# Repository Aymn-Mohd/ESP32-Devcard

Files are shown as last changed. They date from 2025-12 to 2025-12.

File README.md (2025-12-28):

# ESP32DevCard v1 — Credit-Card Sized Powerhouse

A deployment-oriented ESP32-S3 development board for engineers building systems, not desk toys. Real power delivery, integrated sensing, and full breakout in a compact 70 × 50 mm footprint.

The goal: eliminate the wiring mess that causes 80% of prototype failures.

---

## Why This Exists

Most ESP32 boards assume your prototype ends at a breadboard. The moment you attach motors, LED arrays, or anything drawing real current, they fall apart.

This solves that problem directly:

* 4-layer stackup for signal and power integrity
* Multiple power injection points
* Clean grounding discipline and ESD protection
* On-board peripheral support for validation without external modules

This is the board you use when reliability matters from the first test.

---

## Core Capabilities

* ESP32-S3-MINI-1-N8 (Wi-Fi + BLE, dual core)
* ENS210 temperature/humidity sensor (I²C)
* WS2812B RGB indicator (GPIO48)
* USB-C for power/programming with protection circuitry
* 44 usable GPIOs on dual headers
* High-current 5V and 3.3V rails
* 4-layer PCB for controlled return paths

---

## Technical Specifications

| Parameter | Value |
| --- | --- |
| Dimensions | 70 × 50 mm |
| Layers | 4 |
| MCU Flash | 8 MB |
| Operating Voltage | 3.3 V |
| Status LED | WS2812B (GPIO48) |
| On-board Sensor | ENS210 |

---

## Getting Started

1. Plug in via USB-C
2. Flash using the ESP-IDF toolchain or PlatformIO
3. Access peripherals immediately (I²C sensor, indicator LED)

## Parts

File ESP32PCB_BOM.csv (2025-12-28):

Reference | Qty | Part# | Value | Footprint
U1 | 1 | ESP32-S3-MINI-1-N8 | - | ESP32-S3-MINI-1-N8:XCVR_ESP32-S3-MINI-1-N8
U2 | 1 | ESD7104MUTAG | - | Package_DFN_QFN:Diodes_UDFN-10_1.0x2.5mm_P0.5mm
U3 | 1 | TLV75801PDRVR | - | Package_SON:WSON-6-1EP_2x2mm_P0.65mm_EP1x1.6mm
U4 | 1 | ENS210-LQFM | - | Package_DFN_QFN:AMS_QFN-4-1EP_2x2mm_P0.95mm_EP0.7x1.6mm
BOOT1, RESET1 | 2 | PTS810 SJK 250 SMTR LFS | - | Button_Switch_SMD:SW_SPST_PTS810
JUSB1 | 1 | USB4105-GF-A | - | Connector_USB:USB_C_Receptacle_GCT_USB4105-xx-A_16P_TopMnt_Horizontal
D1 | 1 | COM-16347 | - | LED_SMD:LED_WS2812B_PLCC4_5.0x5.0mm_P3.2mm
D2 | 1 | 150060RS75000 | - | LED_SMD:LED_0603_1608Metric
J1, J3 | 2 | 61302211121 | - | Connector_PinHeader_2.54mm:PinHeader_1x22_P2.54mm_Vertical
C1, C3, C4, C5 | 4 | CC0603KRX7R7BB104 | 0.1uF | Capacitor_SMD:C_0603_1608Metric
C2, C6, C7 | 3 | CL10A106MQ8NNNC | 10uF | Capacitor_SMD:C_0603_1608Metric
R1, R2, R8 | 3 | RC0603FR-075K1L | 5.1k | Resistor_SMD:R_0603_1608Metric
R3, R4, R5 | 3 | RC0603FR-0710KL | 10k | Resistor_SMD:R_0603_1608Metric
R6 | 1 | RT0603BRD071ML | 1M | Resistor_SMD:R_0603_1608Metric
R7 | 1 | RC0603FR-07200KL | 200k | Resistor_SMD:R_0603_1608Metric

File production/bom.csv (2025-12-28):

Designator | Footprint | Quantity | Value | LCSC Part #
BOOT1, RESET1 | SW_SPST_PTS810 | 2 | ~
C1, C3, C4, C5 | 0603 | 4 | 0.1uF
C2, C6, C7 | 0603 | 3 | 10uF
D1 | LED_WS2812B_PLCC4_5.0x5.0mm_P3.2mm | 1 | WS2812B
D2 | 0603 | 1 | LED
J1, J3 | PinHeader_1x22_P2.54mm_Vertical | 2 | ~
J2, J4, J5 | PinHeader_1x03_P2.54mm_Vertical | 3 | Conn_01x03_Pin
JUSB1 | USB_C_Receptacle_GCT_USB4105-xx-A_16P_TopMnt_Horizontal | 1 | USB_C_Receptacle_USB2.0
R1, R2, R8 | 0603 | 3 | 5.1k
R3, R4, R5 | 0603 | 3 | 10k
R6 | 0603 | 1 | 1M
R7 | 0603 | 1 | 200k
U1 | XCVR_ESP32-S3-MINI-1-N8 | 1 | ESP32-S3-MINI-1-N8
U2 | Diodes_UDFN-10_1.0x2.5mm_P0.5mm | 1 | ESD7104MUTAG
U3 | WSON-6-1EP_2x2mm_P0.65mm_EP1x1.6mm | 1 | TLV75801PDRV
U4 | AMS_QFN-4-1EP_2x2mm_P0.95mm_EP0.7x1.6mm | 1 | ENS210

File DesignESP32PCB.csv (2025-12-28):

Id | Designator | Footprint | Quantity | Designation | Supplier and ref
1 | J5,J4,J2 | PinHeader_1x03_P2.54mm_Vertical | 3 | Conn_01x03_Pin
2 | R5,R4,R3 | R_0603_1608Metric | 3 | 10k
3 | C5,C1,C4,C3 | C_0603_1608Metric | 4 | 0.1uF
4 | D2 | LED_0603_1608Metric | 1 | LED
5 | R8,R2,R1 | R_0603_1608Metric | 3 | 5.1k
6 | R6 | R_0603_1608Metric | 1 | 1M
7 | U2 | Diodes_UDFN-10_1.0x2.5mm_P0.5mm | 1 | ESD7104MUTAG
8 | C7,C6,C2 | C_0603_1608Metric | 3 | 10uF
9 | J1,J3 | PinHeader_1x22_P2.54mm_Vertical | 2 | ~
10 | R7 | R_0603_1608Metric | 1 | 200k
11 | RESET1,BOOT1 | SW_SPST_PTS810 | 2 | ~
12 | U1 | XCVR_ESP32-S3-MINI-1-N8 | 1 | ESP32-S3-MINI-1-N8
13 | D1 | LED_WS2812B_PLCC4_5.0x5.0mm_P3.2mm | 1 | WS2812B
14 | U3 | WSON-6-1EP_2x2mm_P0.65mm_EP1x1.6mm | 1 | TLV75801PDRV
15 | U4 | AMS_QFN-4-1EP_2x2mm_P0.95mm_EP0.7x1.6mm | 1 | ENS210
16 | JUSB1 | USB_C_Receptacle_GCT_USB4105-xx-A_16P_TopMnt_Horizontal | 1 | USB_C_Receptacle_USB2.0

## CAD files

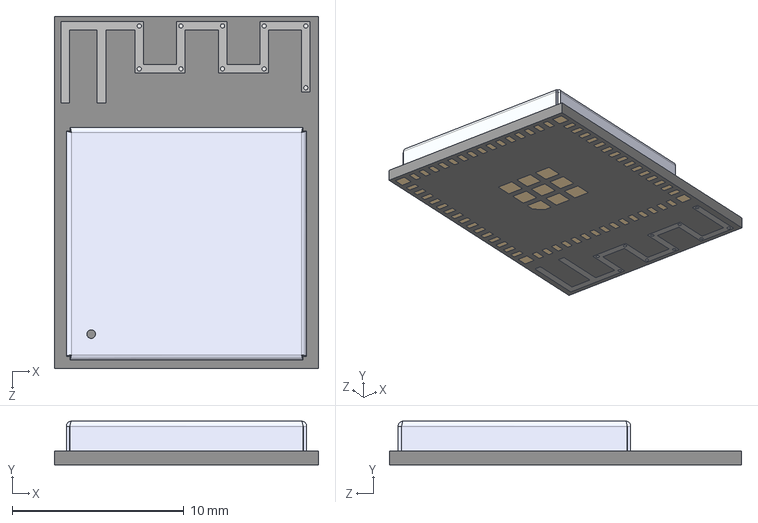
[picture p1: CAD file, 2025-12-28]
ESP32_S3_MINI_1_N8/ESP32-S3-MINI-1-N8.step
15.4 x 2.55 x 20.5 mm

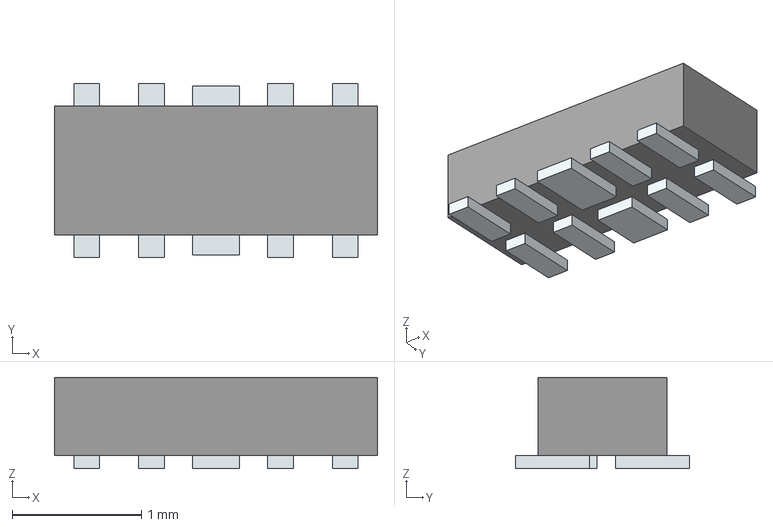
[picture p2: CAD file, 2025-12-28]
LIB_D3V3XA4B10LP-7/3D_MODEL_D3V3XA4B10LP-7.stp
2.50 x 1.35 x 0.705 mm
Pins

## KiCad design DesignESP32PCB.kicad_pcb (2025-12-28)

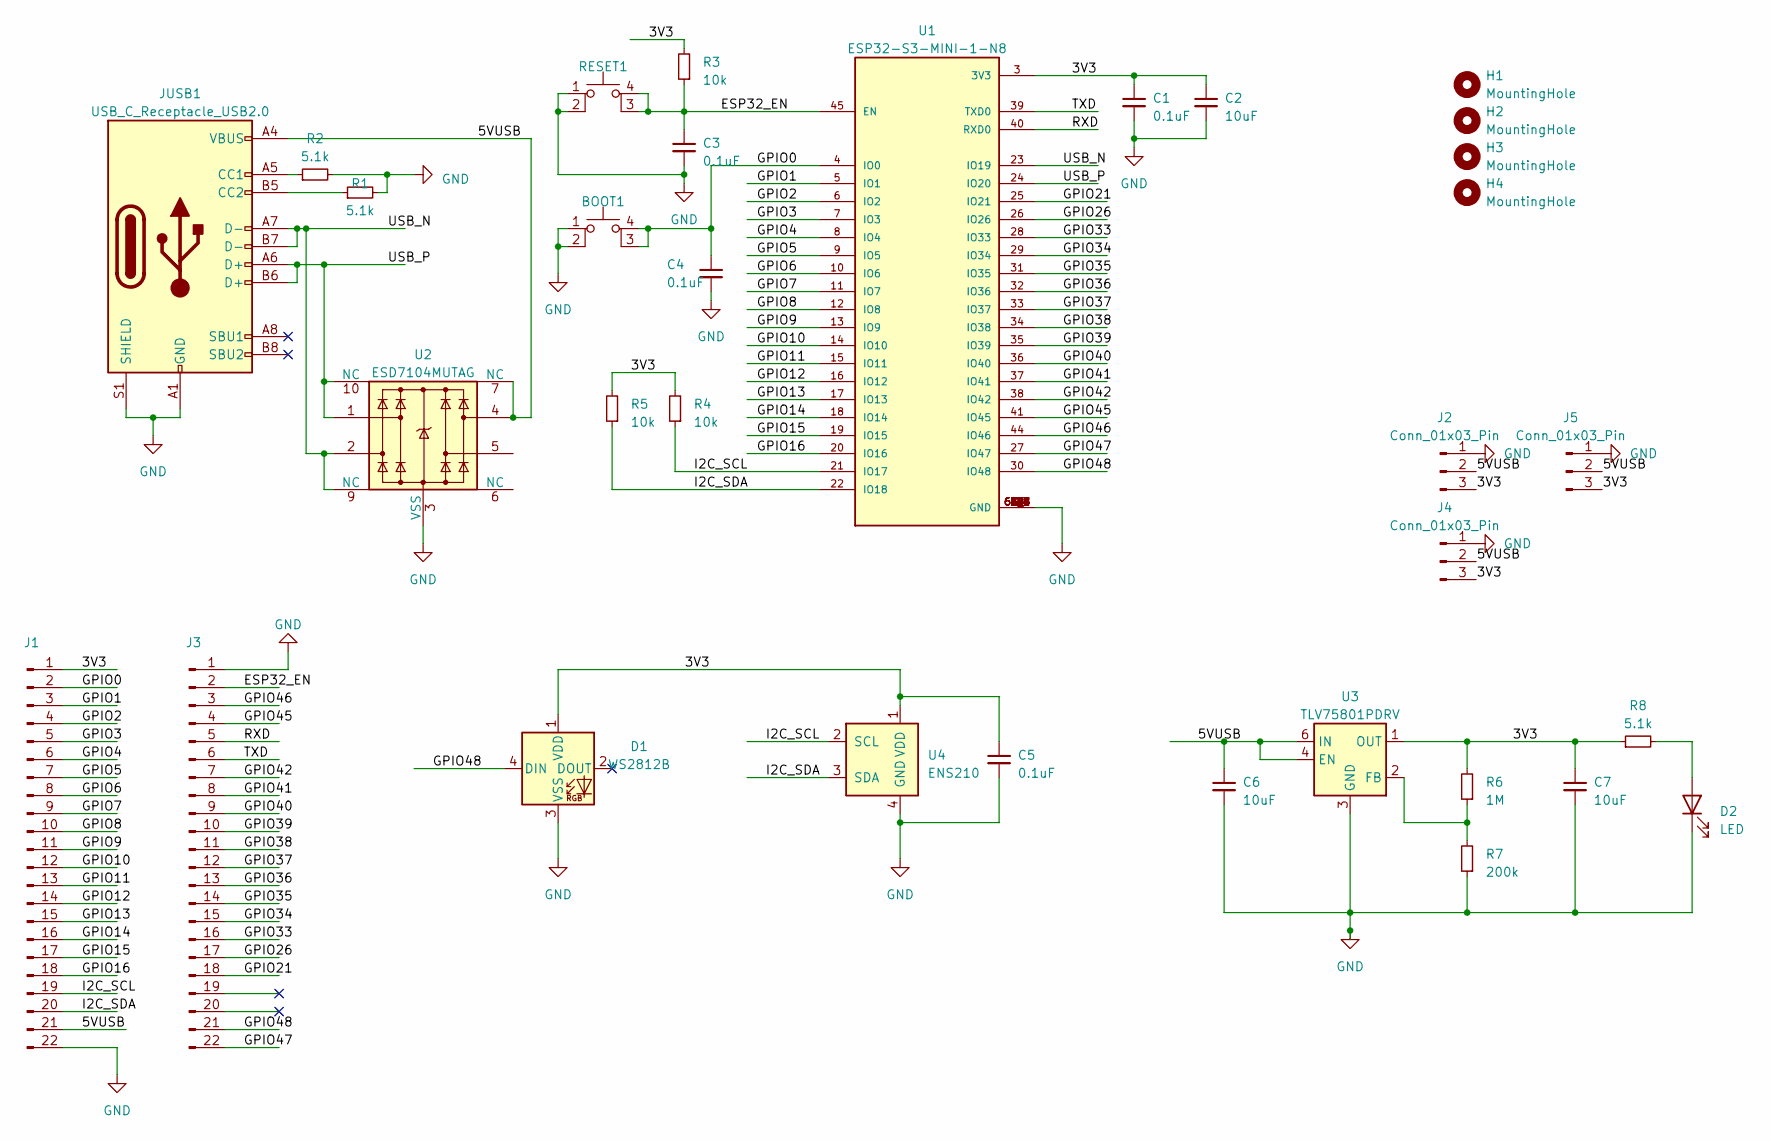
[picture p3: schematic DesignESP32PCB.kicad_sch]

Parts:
BOOT1: SW_SPST_PTS810
C1, C3, C4, C5: 0.1uF; C_0603_1608Metric
C2, C6, C7: 10uF; C_0603_1608Metric
D1: WS2812B; LED_WS2812B_PLCC4_5.0x5.0mm_P3.2mm
D2: LED; LED_0603_1608Metric
H1, H2, H3, H4: MountingHole; MountingHole_2.2mm_M2_Pad_Via
J1, J3: PinHeader_1x22_P2.54mm_Vertical
J2, J4, J5: Conn_01x03_Pin; PinHeader_1x03_P2.54mm_Vertical
JUSB1: USB_C_Receptacle_USB2.0; USB_C_Receptacle_GCT_USB4105-xx-A_16P_TopMnt_Horizontal
R1, R2, R8: 5.1k; R_0603_1608Metric
R3, R4, R5: 10k; R_0603_1608Metric
R6: 1M; R_0603_1608Metric
R7: 200k; R_0603_1608Metric
RESET1: SW_SPST_PTS810
U1: ESP32-S3-MINI-1-N8; XCVR_ESP32-S3-MINI-1-N8; PARTREV v0.6
U2: ESD7104MUTAG; Diodes_UDFN-10_1.0x2.5mm_P0.5mm
U3: TLV75801PDRV; WSON-6-1EP_2x2mm_P0.65mm_EP1x1.6mm
U4: ENS210; AMS_QFN-4-1EP_2x2mm_P0.95mm_EP0.7x1.6mm

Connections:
/3V3: C1.1, C2.1, C5.1, C7.1, D1.1 (VDD), J1.1, J2.3, J4.3, J5.3, R3.2, R4.2, R5.2, R6.2, R8.1, U1.3 (3V3), U3.1 (OUT), U4.1 (VDD)
/5VUSB: C6.1, J1.21, J2.2, J4.2, J5.2, JUSB1.A4 (VBUS), JUSB1.A9 (VBUS), JUSB1.B4 (VBUS), JUSB1.B9 (VBUS), U2.4, U2.7 (NC), U3.4 (EN), U3.6 (IN)
/ESP32_EN: C3.1, J3.2, R3.1, RESET1.3 (K), RESET1.4 (A), U1.45 (EN)
/GPIO0: BOOT1.3 (K), BOOT1.4 (A), C4.1, J1.2, U1.4 (IO0)
/GPIO1: J1.3, U1.5 (IO1)
/GPIO2: J1.4, U1.6 (IO2)
/GPIO3: J1.5, U1.7 (IO3)
/GPIO4: J1.6, U1.8 (IO4)
/GPIO5: J1.7, U1.9 (IO5)
/GPIO6: J1.8, U1.10 (IO6)
/GPIO7: J1.9, U1.11 (IO7)
/GPIO8: J1.10, U1.12 (IO8)
/GPIO9: J1.11, U1.13 (IO9)
/GPIO10: J1.12, U1.14 (IO10)
/GPIO11: J1.13, U1.15 (IO11)
/GPIO12: J1.14, U1.16 (IO12)
/GPIO13: J1.15, U1.17 (IO13)
/GPIO14: J1.16, U1.18 (IO14)
/GPIO15: J1.17, U1.19 (IO15)
/GPIO16: J1.18, U1.20 (IO16)
/GPIO21: J3.18, U1.25 (IO21)
/GPIO26: J3.17, U1.26 (IO26)
/GPIO33: J3.16, U1.28 (IO33)
/GPIO34: J3.15, U1.29 (IO34)
/GPIO35: J3.14, U1.31 (IO35)
/GPIO36: J3.13, U1.32 (IO36)
/GPIO37: J3.12, U1.33 (IO37)
/GPIO38: J3.11, U1.34 (IO38)
/GPIO39: J3.10, U1.35 (IO39)
/GPIO40: J3.9, U1.36 (IO40)
/GPIO41: J3.8, U1.37 (IO41)
/GPIO42: J3.7, U1.38 (IO42)
/GPIO45: J3.4, U1.41 (IO45)
/GPIO46: J3.3, U1.44 (IO46)
/GPIO47: J3.22, U1.27 (IO47)
/GPIO48: D1.4 (DIN), J3.21, U1.30 (IO48)
/I2C_SCL: J1.19, R4.1, U1.21 (IO17), U4.2 (SCL)
/I2C_SDA: J1.20, R5.1, U1.22 (IO18), U4.3 (SDA)
/RXD: J3.5, U1.40 (RXD0)
/TXD: J3.6, U1.39 (TXD0)
/USB_N: JUSB1.A7 (D-), JUSB1.B7 (D-), U1.23 (IO19), U2.2, U2.9 (NC)
/USB_P: JUSB1.A6 (D+), JUSB1.B6 (D+), U1.24 (IO20), U2.1, U2.10 (NC)
GND: BOOT1.1, BOOT1.2, C1.2, C2.2, C3.2, C4.2, C5.2, C6.2, C7.2, D1.3 (VSS), D2.1 (K), J1.22, J2.1, J3.1, J4.1, J5.1, JUSB1.A1 (GND), JUSB1.A12 (GND), JUSB1.B1 (GND), JUSB1.B12 (GND), JUSB1.S1 (SHIELD), R1.2, R2.2, R7.1, RESET1.1, RESET1.2, U1.1 (GND), U1.2 (GND), U1.42 (GND), U1.43 (GND), U1.46 (GND), U1.47 (GND), U1.48 (GND), U1.49 (GND), U1.50 (GND), U1.51 (GND), U1.52 (GND), U1.53 (GND), U1.54 (GND), U1.55 (GND), U1.56 (GND), U1.57 (GND), U1.58 (GND), U1.59 (GND), U1.60 (GND), U1.61 (GND), U1.61_1 (GND), U1.61_2 (GND), U1.61_3 (GND), U1.61_4 (GND), U1.61_5 (GND), U1.61_6 (GND), U1.61_7 (GND), U1.61_8 (GND), U1.62 (GND), U1.63 (GND), U1.64 (GND), U1.65 (GND), U2.3 (VSS), U2.8 (VSS), U3.3 (GND), U3.7 (GND), U4.4 (GND), U4.5 (GND)
unnamed: D2.2 (A), R8.2
unnamed: JUSB1.A5 (CC1), R2.1
unnamed: JUSB1.B5 (CC2), R1.1
unnamed: R6.1, R7.2, U3.2 (FB)

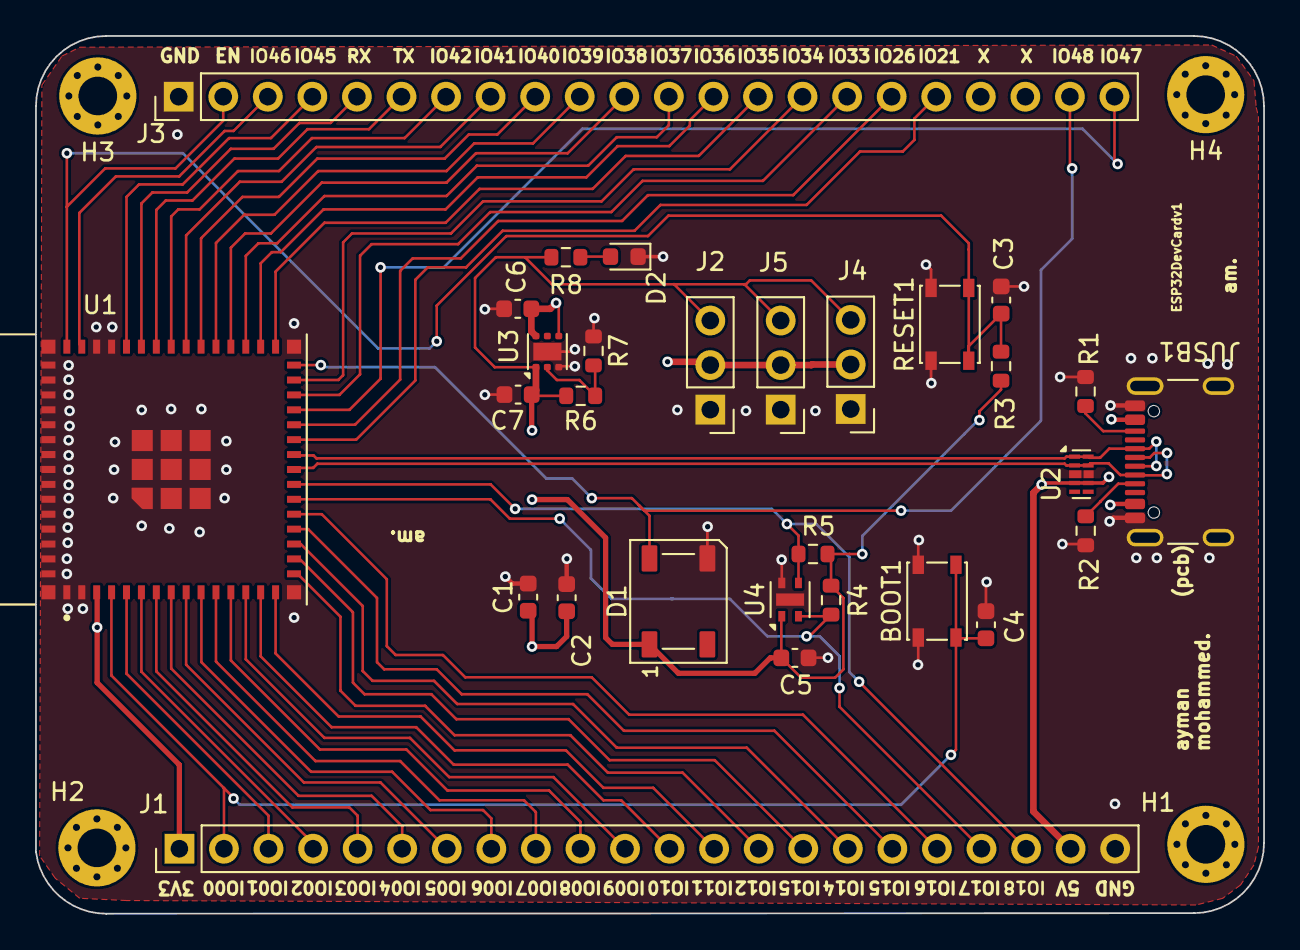
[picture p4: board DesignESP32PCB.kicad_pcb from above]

Board: 4 copper layers, 70.0 x 50.0 mm, 33 parts (0 on the bottom side), 47 nets.
